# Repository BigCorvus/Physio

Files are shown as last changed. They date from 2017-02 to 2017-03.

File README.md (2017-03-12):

# Physio
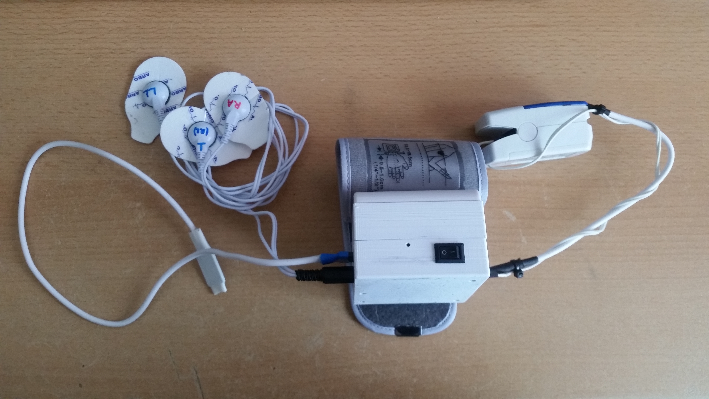
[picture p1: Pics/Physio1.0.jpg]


My take on an (almost) open source development platform for a versatile wireless monitoring device that combines ECG, impedance pneumography, photoplethysmography, SPO2 calculation, galvanic skin response, NIBP wrist measurement as well as well as body temperature measurement in one wearable. 

Physio is based on a CK101 wrist blood pressure monitor, a CMS50C pulse oximeter, an ADS1292R analog front end for ECG and impedance pneumography (respiration monitoring via ECG electrodes), a MAX30205 human body temperature sensor and an ADXL345 accelerometer. The GSR measurement is also working fine so far, but it's interfering with the ADS1292R so only one of them can be used at a time. For instruction on hacking the CK101 and CMS50C see  my blog posts http://www.thinkering.de/cms/?p=833 and http://www.thinkering.de/cms/?p=864. and A Teensy 3.2 ties everythings together and uses an HC-05 bluetooth module for communication.
The carrier PCB of the current Physio version is designed for the great ADS1292R breakout board by protocentral->https://github.com/Protocentral/ADS1292rShield_Breakout

The Android app is based on the Amarino platform, so you have to download and install the Amarino App in order for this app to work (https://storage.googleapis.com/google-code-archive-downloads/v2/code.google.com/amarino/Amarino_2_v0_55.apk). The recording feature is not working yet and will be improved in the future.

In order to get the best ECG and respiration data I recommend placing the electrodes according to the "Einthoven II" lead.

Short demo video with crappy electrodes: https://youtu.be/U5jK3dh345U

Note: this is not a medical device, but a development platform for educational and research purposes. I'm assuming you know what you're doing.

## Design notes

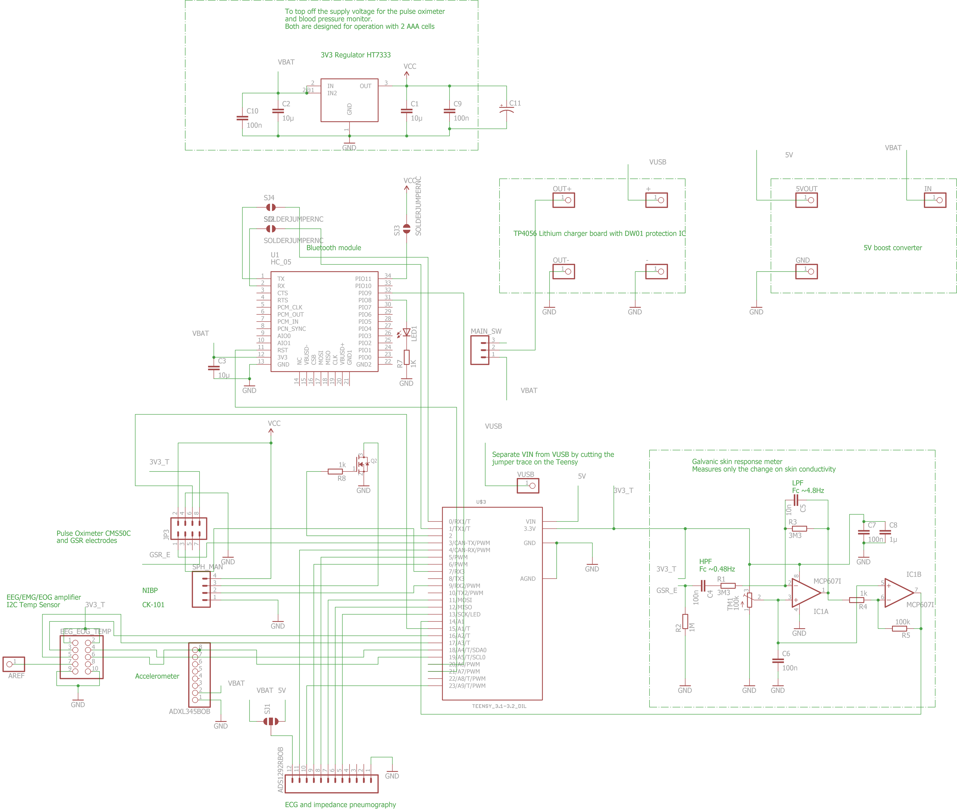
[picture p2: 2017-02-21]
Hardware/Physio_v1.0.png

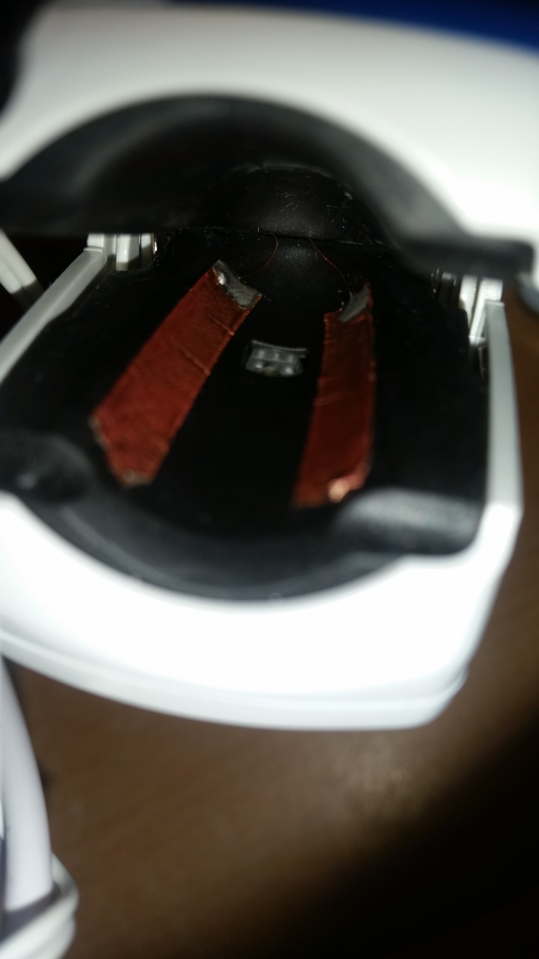
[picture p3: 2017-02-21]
Pics/GSR_pulseox.jpg

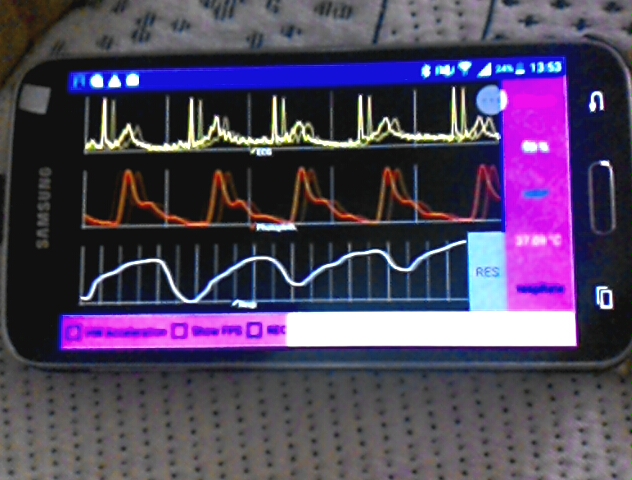
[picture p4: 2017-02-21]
Pics/android app.jpg

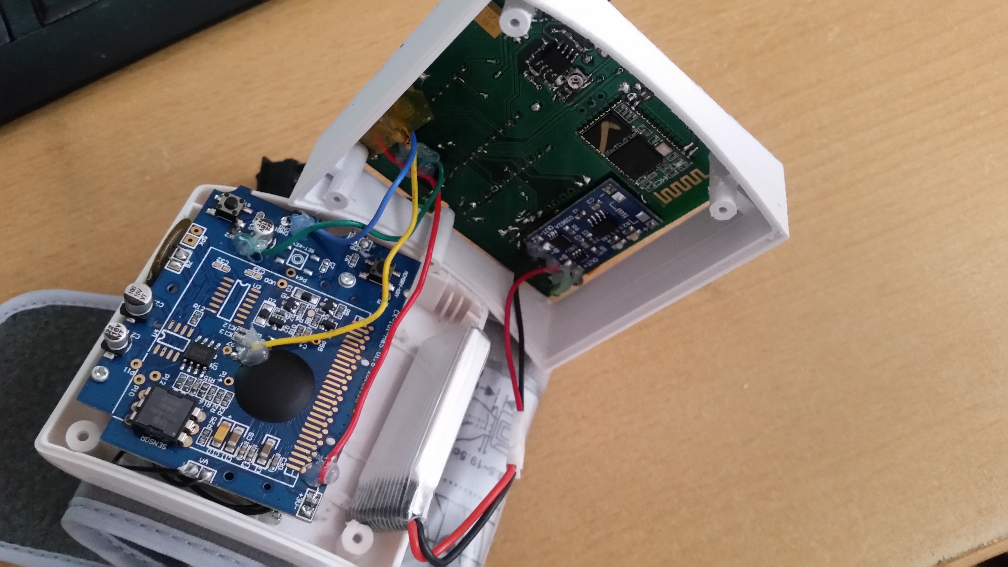
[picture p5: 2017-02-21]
Pics/Physio1.0inside.jpg

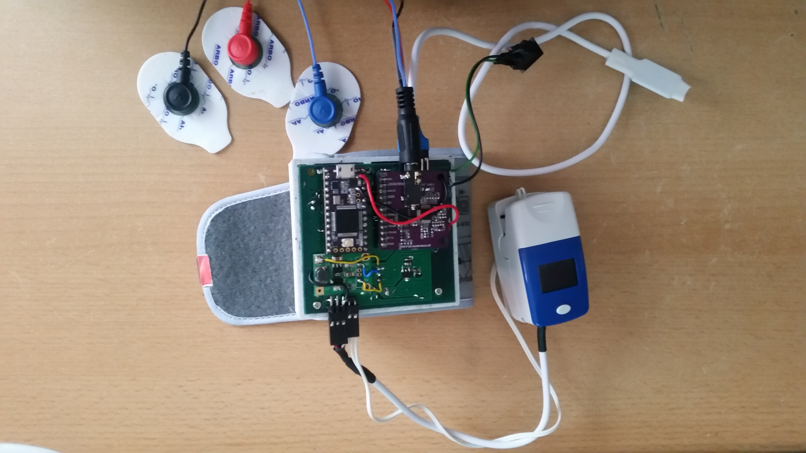
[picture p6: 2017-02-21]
Pics/Physio1.0inside2.jpg

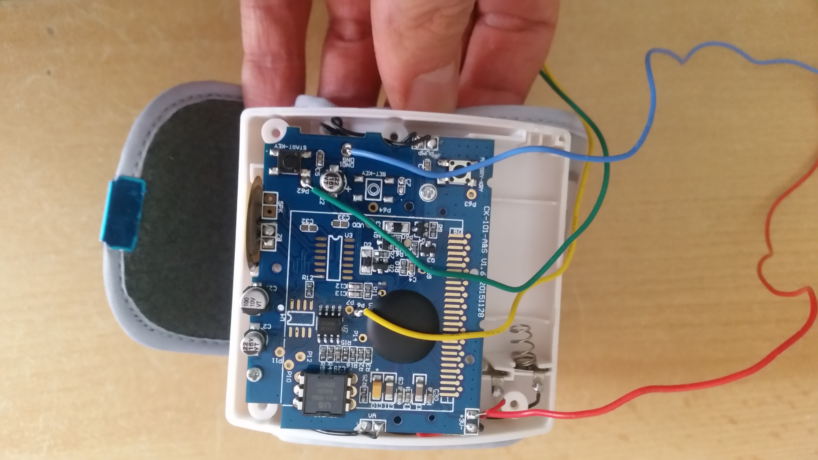
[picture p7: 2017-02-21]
Pics/CK101connections.jpg

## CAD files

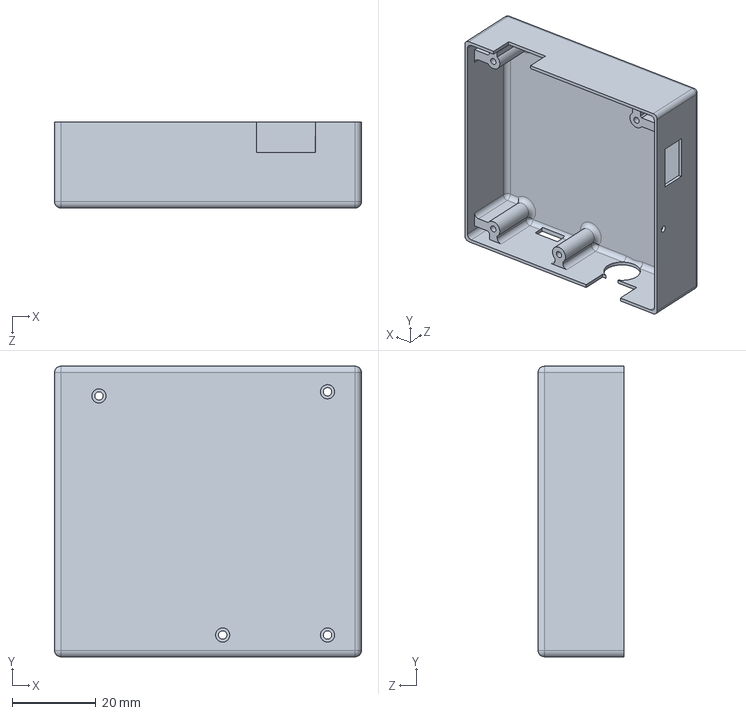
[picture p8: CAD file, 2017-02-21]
Enclosure Design/Physio_enclTop.SLDPRT
73.2 x 69.3 x 20.5 mm

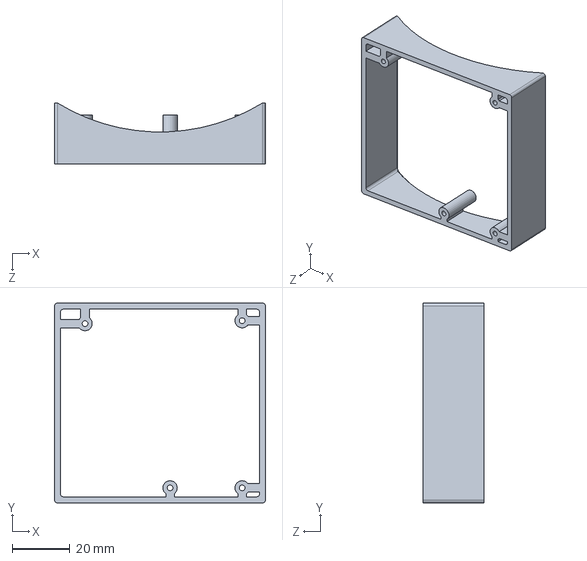
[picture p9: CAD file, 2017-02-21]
Enclosure Design/Physio_encl.SLDPRT
73.2 x 69.3 x 21.0 mm

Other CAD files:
Enclosure Design/Physio_encl.STL
Enclosure Design/Physio_enclTop.STL

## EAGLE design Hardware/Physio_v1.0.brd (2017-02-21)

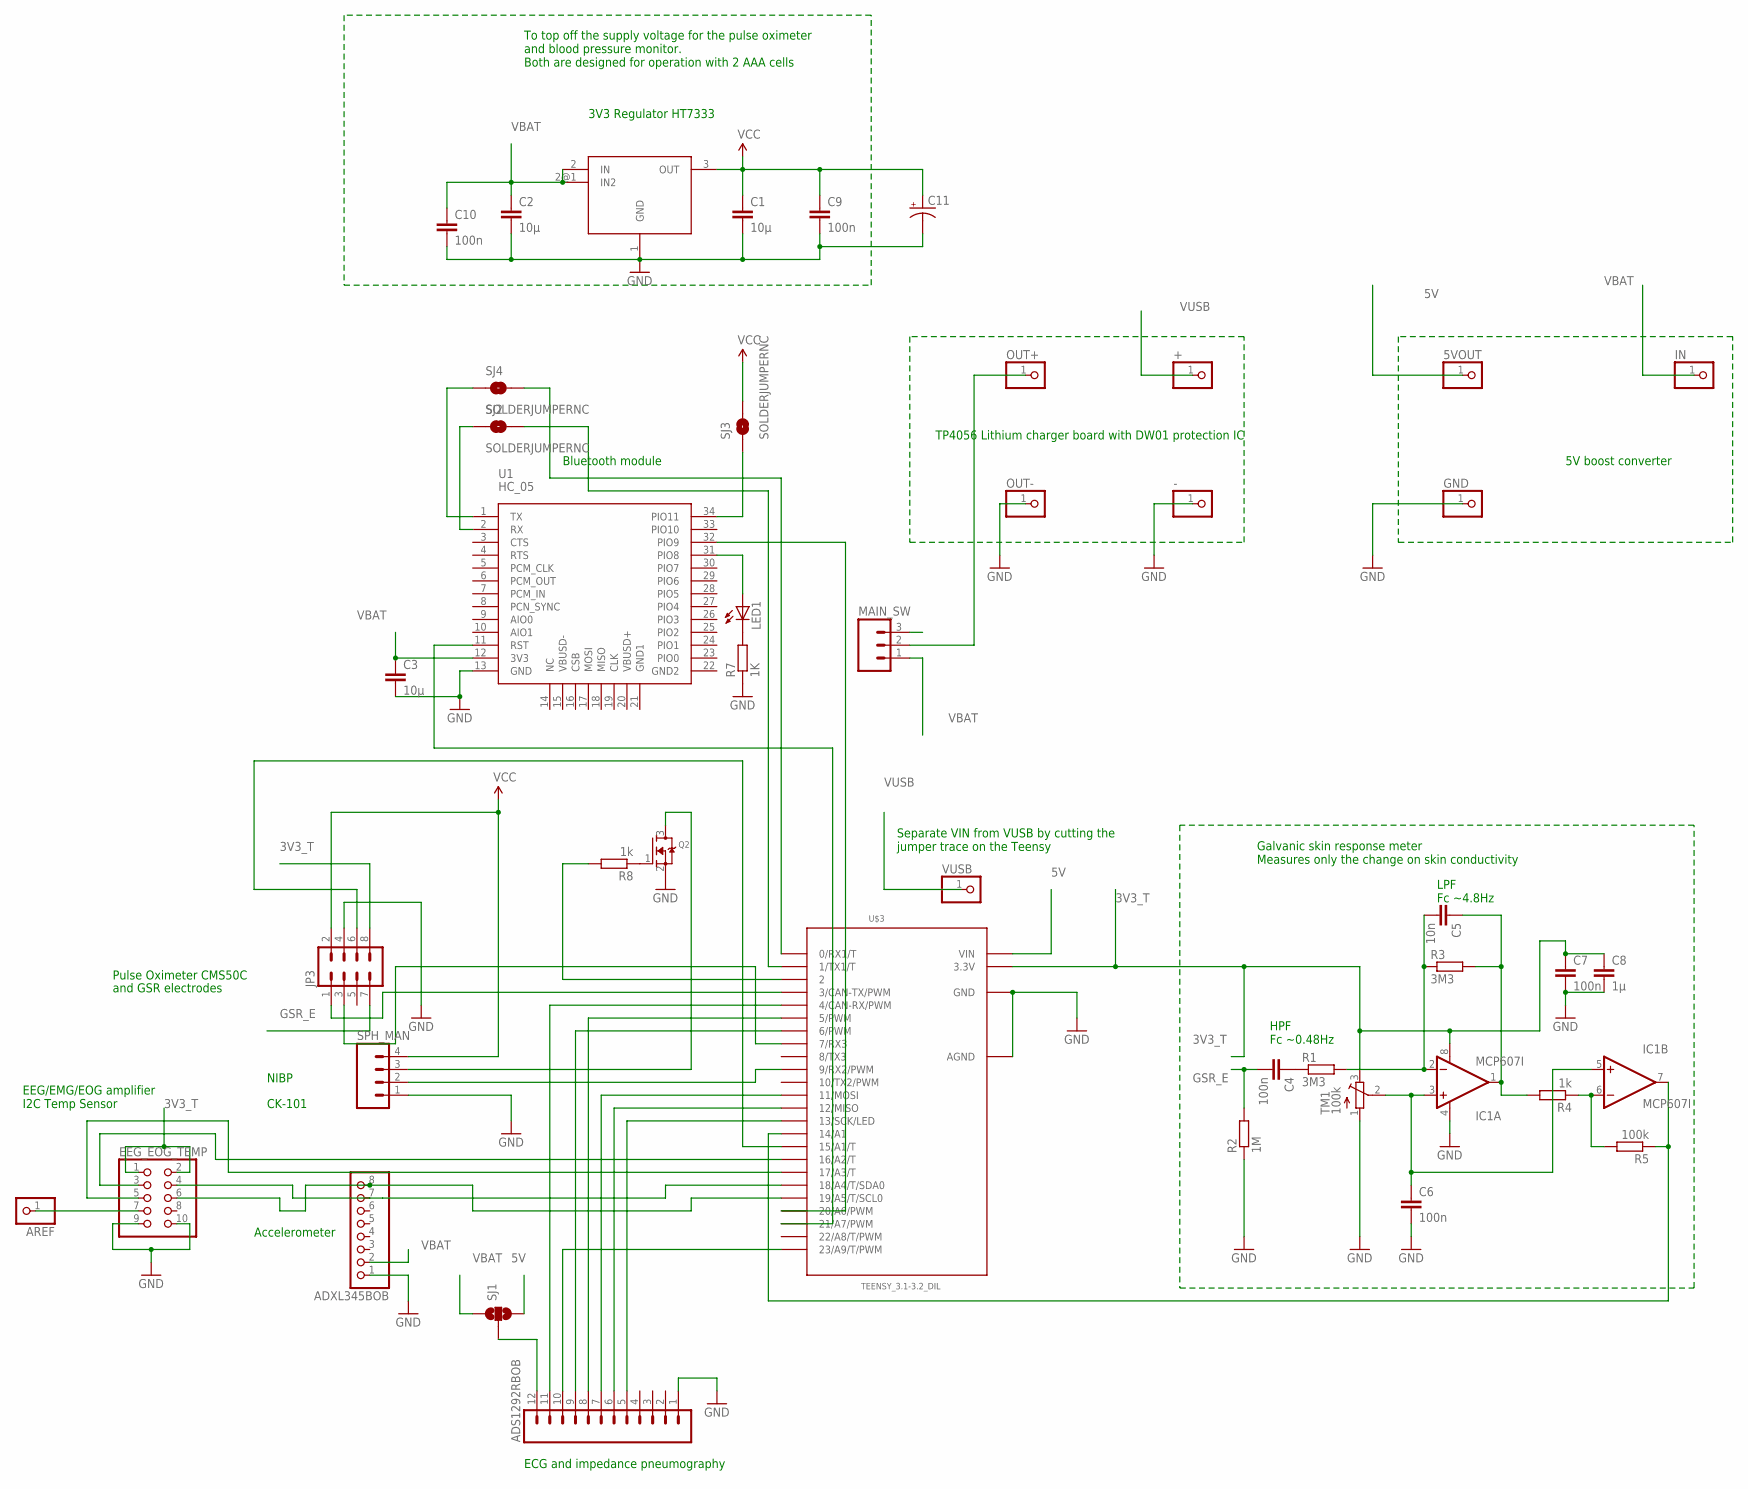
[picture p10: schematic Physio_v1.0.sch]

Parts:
5VOUT: PINHD-1X1; 1X01
+: PINHD-1X1; 1X01
-: PINHD-1X1; 1X01
ADS1292RBOB: M12PTH; 1X12
ADXL345BOB: PINHD-1X8CLEANBIG; 1X08-CLEANBIG
AREF: PINHD-1X1; 1X01
C1, C2, C3: 10µ; C0805K
C4, C6, C7, C9, C10: 100n; C0603K
C5: 10n; C0603K
C8: 1µ; C0603K
C11: CAP_POL7343; EIA7343
EEG_EOG_TEMP: PINHD-2X5/90; 2X05/90
GND: PINHD-1X1; 1X01
IC1: MCP607I; SO08
IN: PINHD-1X1; 1X01
JP3: M04X2; 2X4
LED1: LEDCHIP-LED0805; CHIP-LED0805
MAIN_SW: M03PTH; 1X03
OUT+: PINHD-1X1; 1X01
OUT-: PINHD-1X1; 1X01
Q2: MOSFET-NREFLOW; SOT23
R1, R3: 3M3; R0603
R2: 1M; R0603
R4, R8: 1k; R0603
R5: 100k; R0603
R7: 1K; R0603
SJ1: SOLDERJUMPER_2WAY-OLDT; SJ_2
SJ2, SJ3, SJ4: SOLDERJUMPERNC; SJ_2S
SPH_MAN: M04PTH; 1X04
TM1: 100k; TC33X
U1: HC_05; BLUETOOTH_SMD
U$2: HT7333; SOT89
U$3: TEENSY_3.1-3.2_DIL; TEENSY_3.0-3.2&LC_DIL
VUSB: PINHD-1X1; 1X01

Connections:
3V3_T: C7.1, C8.1, EEG_EOG_TEMP.1, EEG_EOG_TEMP.2, IC1.8 (V+), JP3.8, TM1.3 (E), U$3.3.3V
5V: 5VOUT.1, SJ1.3, U$3.VIN
GND: -.1, ADS1292RBOB.1, ADXL345BOB.1, C1.2, C2.2, C3.2, C6.2, C7.2, C8.2, C9.2, C10.2, C11.C (-), EEG_EOG_TEMP.9, EEG_EOG_TEMP.10, GND.1, IC1.4 (V-), JP3.4, OUT-.1, Q2.2 (S), R2.1, R7.1, SPH_MAN.1, TM1.1 (A), U1.13 (GND), U$2.1 (GND), U$3.AGND, U$3.GND
GSR_E: C4.2, JP3.7, R2.2
unnamed: JP3.1, U$3.3 (3/CAN-TX/PWM)
unnamed: SPH_MAN.2, U$3.9 (9/RX2/PWM)
unnamed: JP3.3, U$3.7 (7/RX3)
unnamed: Q2.3 (D), SPH_MAN.3
unnamed: SJ4.2, U$3.0 (0/RX1/T)
unnamed: SJ2.2, U$3.1 (1/TX1/T)
unnamed: ADS1292RBOB.7, U$3.11 (11/MOSI)
unnamed: ADS1292RBOB.6, U$3.12 (12/MISO)
unnamed: ADS1292RBOB.5, U$3.13 (13/SCK/LED)
unnamed: ADS1292RBOB.9, U$3.6 (6/PWM)
unnamed: ADS1292RBOB.8, U$3.5 (5/PWM)
unnamed: ADS1292RBOB.11, U$3.4 (4/CAN-RX/PWM)
unnamed: ADS1292RBOB.10, U$3.23/A9 (23/A9/T/PWM)
unnamed: C5.2, IC1.2 (-IN), R1.2, R3.1
unnamed: C5.1, IC1.1 (OUT), R3.2, R4.2
unnamed: C6.1, IC1.3 (+IN), IC1.5 (+IN), TM1.2 (S)
unnamed: C4.1, R1.1
unnamed: SJ4.1, U1.1 (TX)
unnamed: IC1.6 (-IN), R4.1, R5.2
unnamed: IC1.7 (OUT), R5.1, U$3.14/A0 (14/A1)
unnamed: SJ2.1, U1.2 (RX)
unnamed: JP3.6, U$3.15/A1 (15/A1/T)
unnamed: ADXL345BOB.8, EEG_EOG_TEMP.6, U$3.19/A5 (19/A5/T/SCL0)
unnamed: ADXL345BOB.7, EEG_EOG_TEMP.4, U$3.18/A4 (18/A4/T/SDA0)
unnamed: LED1.C, R7.2
unnamed: LED1.A, U1.31 (PIO8)
unnamed: EEG_EOG_TEMP.3, U$3.16/A2 (16/A2/T)
unnamed: EEG_EOG_TEMP.5, U$3.17/A3 (17/A3/T)
unnamed: R8.2, U$3.2
unnamed: ADS1292RBOB.12, SJ1.2
unnamed: Q2.1 (G), R8.1
unnamed: AREF.1, EEG_EOG_TEMP.7
unnamed: MAIN_SW.2, OUT+.1
unnamed: U1.32 (PIO9), U$3.20/A6 (20/A6/PWM)
unnamed: U1.11 (RST), U$3.21/A7 (21/A7/PWM)
unnamed: SJ3.1, U1.34 (PIO11)
VBAT: ADXL345BOB.2, C2.1, C3.1, C10.1, IN.1, MAIN_SW.1, SJ1.1, U1.12 (3V3), U$2.2 (IN), U$2.2@1 (IN2)
VCC: C1.1, C9.1, C11.A (+), JP3.2, SJ3.2, SPH_MAN.4, U$2.3 (OUT)
VUSB: +.1, VUSB.1

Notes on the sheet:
Galvanic skin response meter Measures only the change on skin conductivity
HPF Fc ~0.48Hz
LPF Fc ~4.8Hz
ECG and impedance pneumography
Accelerometer
NIBP
CK-101
Pulse Oximeter CMS50C
EEG/EMG/EOG amplifier I2C Temp Sensor
3V3 Regulator HT7333
Separate VIN from VUSB by cutting the jumper trace on the Teensy
TP4056 Lithium charger board with DW01 protection IC
5V boost converter
To top off the supply voltage for the pulse oximeter and blood pressure monitor. Both are designed for operation with 2 AAA cells
Bluetooth module
and GSR electrodes

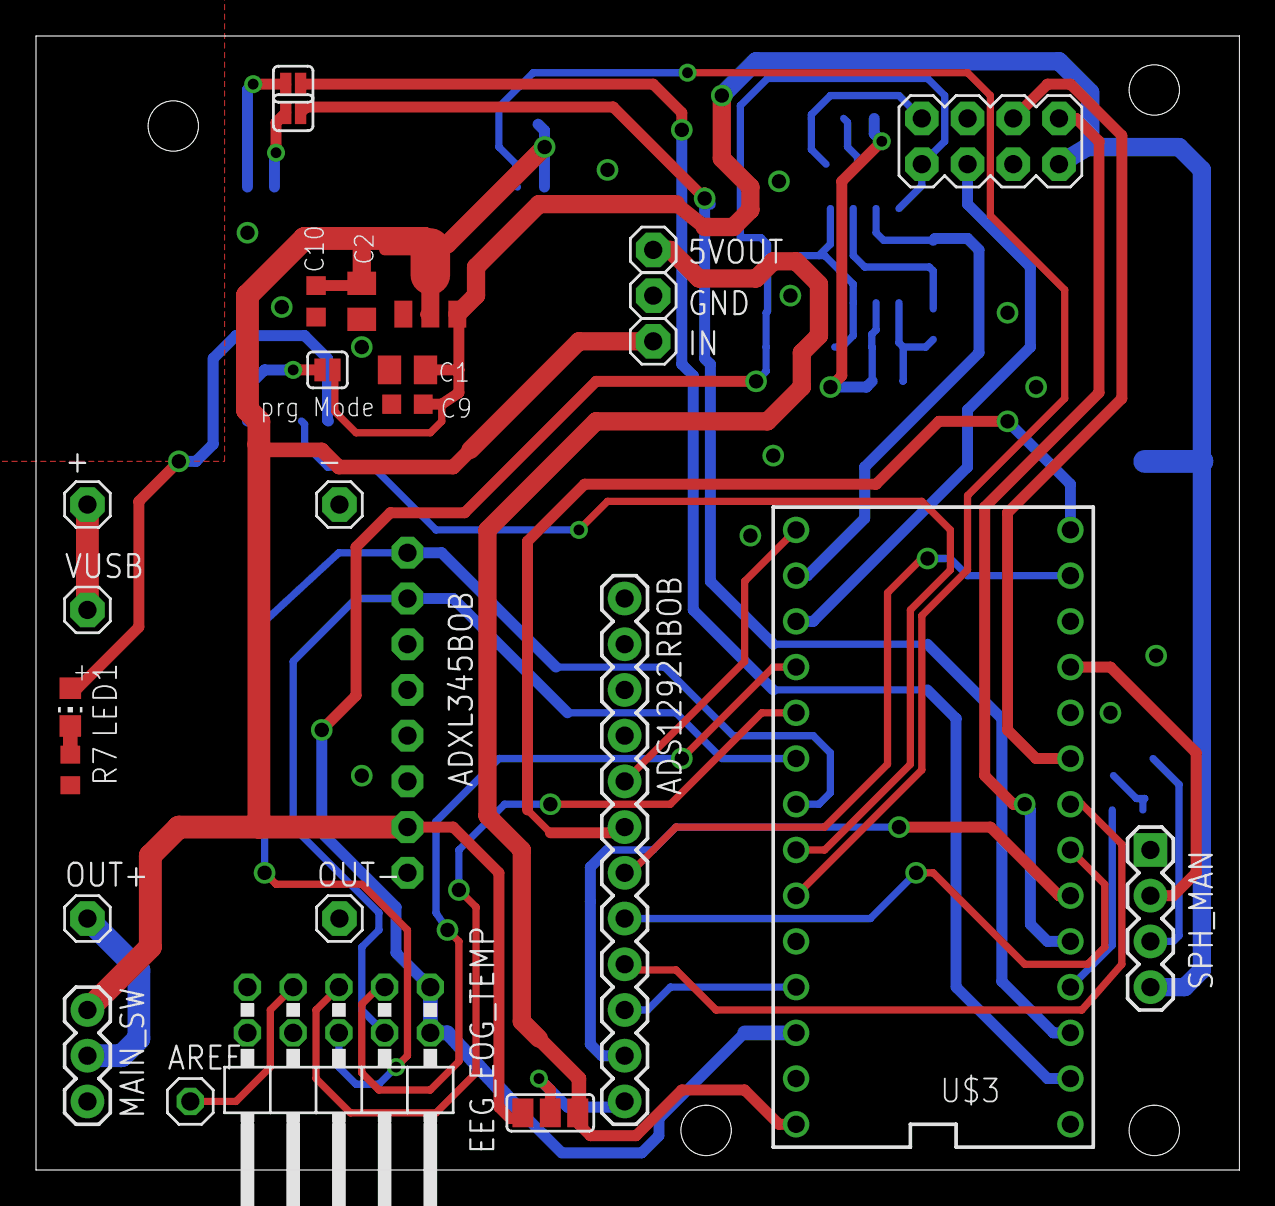
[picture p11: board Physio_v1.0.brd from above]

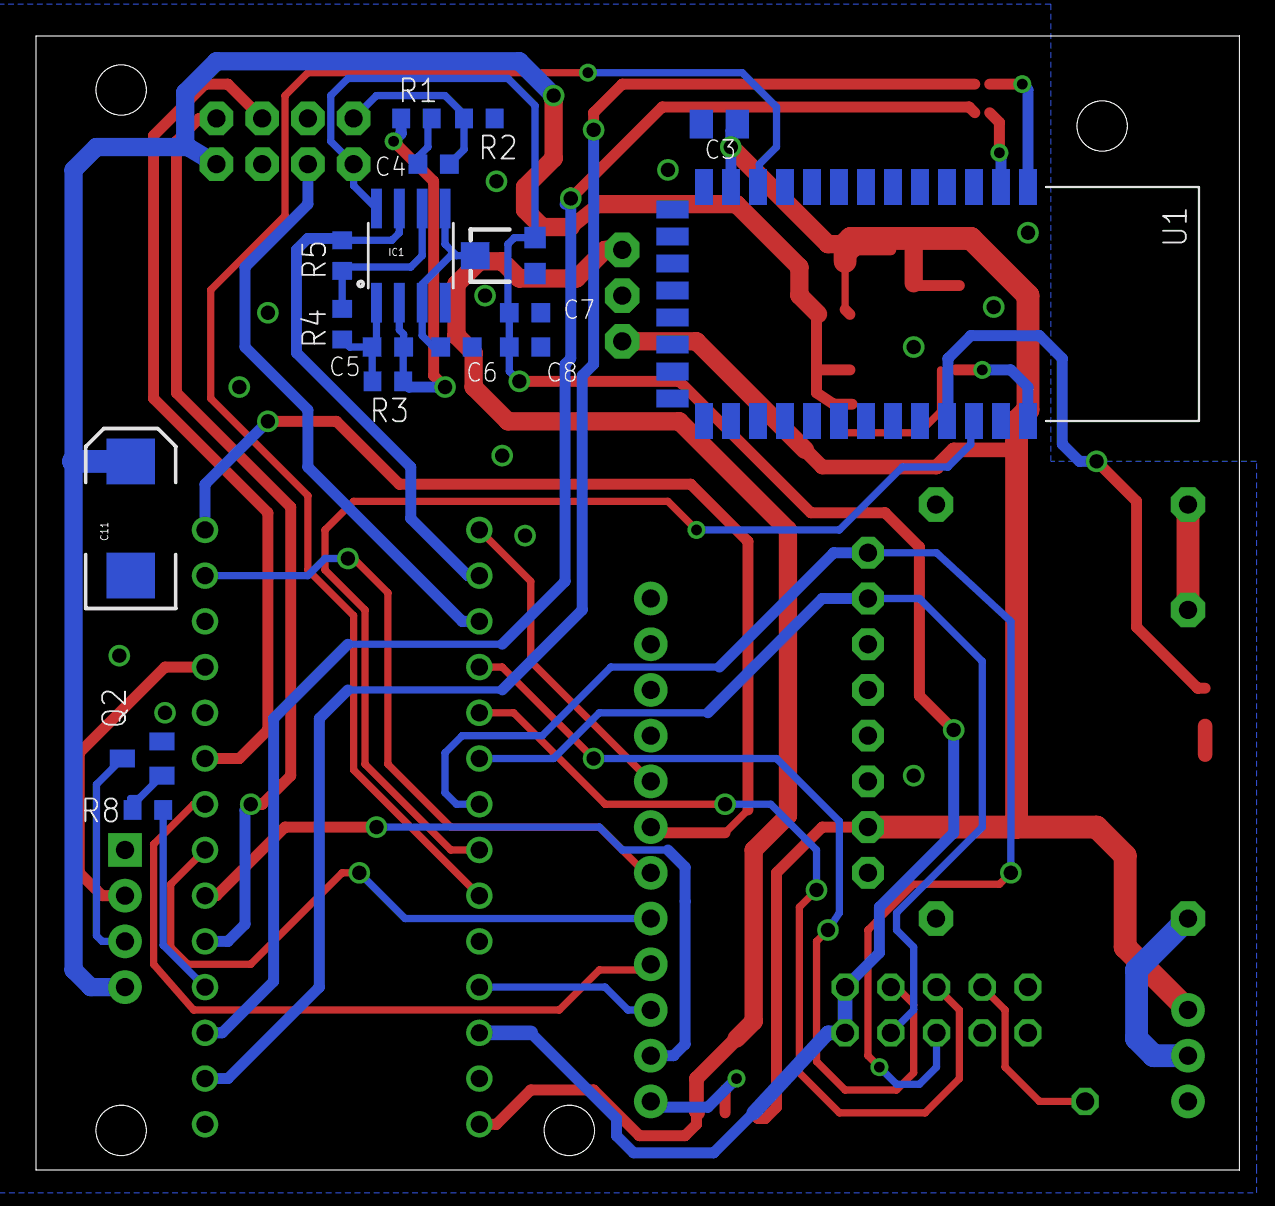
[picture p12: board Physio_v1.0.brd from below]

Board: 2 copper layers, 66.9 x 63.0 mm, 44 parts (17 on the bottom side), 43 nets.

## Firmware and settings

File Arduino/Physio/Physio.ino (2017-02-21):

/*
  Patient Monitor with Blood pressure monitor CK-101 and Pulse oximeter CONTEC CMS 50C
  On Teensy 3.1
*/
// Arduino Wire library is required if I2Cdev I2CDEV_ARDUINO_WIRE implementation
// is used in I2Cdev.h
#include "Wire.h"
// I2Cdev and ADXL345 must be installed as libraries, or else the .cpp/.h files
// for both classes must be in the include path of your project
#include "I2Cdev.h"
#include "ADXL345.h"

#include <ads1292r.h>
#include <SPI.h>
#include <MeetAndroid.h> //modified library that uses Serial1 instead of Serial!
#include "ClosedCube_MAX30205.h"


//--------------------------------------ADS1292R stuff----------------------------------

uint8_t DataPacketHeader[16];
ads1292r ADS1292;
//Packet format
#define  CES_CMDIF_PKT_START_1   0x0A
#define CES_CMDIF_PKT_START_2   0xFA
#define CES_CMDIF_TYPE_DATA   0x02
#define CES_CMDIF_PKT_STOP    0x0B

uint8_t data_len = 8;
unsigned long time;

volatile byte SPI_RX_Buff[150] ;
volatile static int SPI_RX_Buff_Count = 0;
volatile char *SPI_RX_Buff_Ptr;
volatile int Responsebyte = false;
volatile unsigned int pckt = 0 , buff = 0, t = 0 , jone = 0, jtwo = 0;
volatile unsigned long int RESP_Ch1_Data[150], ECG_Ch2_Data[150];
volatile unsigned char datac[150];
unsigned long uecgtemp = 0, Pkt_Counter = 0;
long ECG, RESP = 0;
signed long secgtemp = 0;
volatile int i;
volatile long packet_counter = 0;
//--------------------------------------ADS1292R stuff----------------------------------

// class default I2C address is 0x53
// specific I2C addresses may be passed as a parameter here
// ALT low = 0x53 (default for SparkFun 6DOF board)
// ALT high = 0x1D
ADXL345 accel;
ClosedCube_MAX30205 max30205; //human temperature sensor connected over I2C
// declare MeetAndroid so that you can call functions with it
MeetAndroid meetAndroid;
int16_t ax, ay, az;


//pins for switching the start buttons on the medical gadgets

#define TRIG_RR 2 //has to be pulled to ground to start the CK-101
#define TRIG_PULSEOX 3 // has to be pulled to 3.3V to start the CMS50C
#define RST_PULSEOX 15

//packet management bytes for the Amarino Android app
char startFlag = 18;
char ack = 19;
char delimiter = 59; //';' in case we use more than 1 channel

//vars for RR
boolean isMeasuringRR = false;
boolean RRdoneByteCame = false;
boolean successfulRR = false;
boolean readSpecialPacket = false;
boolean errorRR = false;
char incomingRRbyte;
int byteCntRR = 0;
char pulseCurve_RR;
char cuffPressRR;
char systRR;
char diastRR;
char HR_RR;

//vars for pulseOx
char incomingPulseOxbyte;
unsigned int byteCntPulse = 0;
char pulseCurve_PulseOx = 0;
char SPO2;
char HR_PulseOx;
boolean lastBitPulseOx = 0; //the MSB of the heart rate byte is hidden in a different byte - the one that holds the bar graph data

//timer vars
unsigned long GSRTmr, temperatureTmr = 0;
unsigned long sampIntGSR=50000;//sample interval for GSR measurement, Accelerometer, impedance pneumography value
unsigned long sampIntTemp=500000;//sample interval for the temperature sensor

unsigned long RRtrigTmr=0;
unsigned long RRtrigInt=200000; // length of the pulse that triggers the CK-101 button via NPN transistor
unsigned long pulseOxTrigTmr=0;
unsigned long pulseOxTrigInt=600000; // length of the pulse that triggers the CMS50C
unsigned long pulseOxRstTmr=0;
unsigned long pulseOxRstInt=800000;
boolean triggered = false;
boolean triggeredOx = false;
boolean resettedOx = false;
//----------------------------------------------------------------------------------------------------

void setup() {
  // initialize serial:
  Serial1.begin(115200); // Bluetooth port
  Serial2.begin(9600); // Blood pressure monitor CK-101 port
  Serial3.begin(4800, SERIAL_8E1); // Pulse oximeter CONTEC CMS 50C, annoying fact: it has EVEN PARITY!

  // initalize the  data ready and chip select pins for ADS1292R:
  pinMode(ADS1292_DRDY_PIN, INPUT);  //6
  pinMode(ADS1292_CS_PIN, OUTPUT);    //7
  pinMode(ADS1292_START_PIN, OUTPUT);  //5
  pinMode(ADS1292_PWDN_PIN, OUTPUT);  //4

  // make the pins outputs:
  pinMode(RST_PULSEOX, OUTPUT);
  pinMode(TRIG_RR, OUTPUT);
  pinMode(TRIG_PULSEOX, OUTPUT);
  
  digitalWrite(RST_PULSEOX, HIGH);
  digitalWrite(TRIG_RR, LOW);
  
  triggerOx(); //turn on the PulseOx
  // join I2C bus (I2Cdev library doesn't do this automatically)
  Wire.begin();
  accel.initialize();
  max30205.begin(0x48); //initialize the temp sensor
  //initalize ADS1292 slave
  ADS1292.ads1292_Init();
  //ADS1292.ads1292_Reset();
  // register callback functions, which will be called when an associated event occurs.
  meetAndroid.registerFunction(measureRR, 'b');


  GSRTmr=micros(); //GSR, RESP, ACC are sampled simultaneously
  temperatureTmr=micros(); //temperature is sampled slower
}
//----------------------------------------------------------------------------------------------------

void loop() {

//waiting to pull TRIG_RR LOW again to turn the NPN transistor off
  if((micros()-RRtrigTmr)>RRtrigInt && triggered == true){
    digitalWrite(TRIG_RR, LOW);
    triggered=false;
  }

  //waiting to pull TRIG_PULSEOX LOW again 
  if((micros()-pulseOxTrigTmr)>pulseOxTrigInt && triggeredOx == true){
    digitalWrite(TRIG_PULSEOX, LOW);
    triggeredOx=false;
  }
  
 //waiting pulseOxRstInt long after Reset and then trigger the Oximeter to turn it on again 
 //probably not necessary
  if((micros()-pulseOxRstTmr)>pulseOxRstInt && resettedOx == true){
     byteCntPulse=0; //clean up after reset
    resettedOx=false;
    triggerOx();
  }
  
/*
  //waiting to pull RST_PULSEOX HIGH again 
  if((micros()-pulseOxRstTmr)>pulseOxRstInt && resettedOx == true){
    digitalWrite(RST_PULSEOX, HIGH);
    resettedOx=false;
//after reset push its button
    digitalWrite(TRIG_PULSEOX, HIGH); //push its button
           pulseOxTrigTmr=micros();
           triggeredOx=true;
  }

  */
  
  sampleTemperature();

  sampleDevices();

  meetAndroid.receive(); // you need to keep this in your loop() to receive events

  readADS();

  readPulseOx();

  readBloodPress();

}

//------------------------------------functions for the components--------------------------------------------------

void sampleDevices(){
  //sample GSR, Respiration, Accelerometer
  if((micros() - GSRTmr) > sampIntGSR){
  Serial1.print(startFlag);
  Serial1.print("G");
  //Serial1.print(delimiter);
  Serial1.print(analogRead(A0), DEC);
  Serial1.print(delimiter);
  Serial1.print(RESP, DEC);
  //Serial1.print(ack);

  // read raw accel measurements from device
  accel.getAcceleration(&ax, &ay, &az);
  //Serial1.print(startFlag);
  //Serial1.print("A");
  Serial1.print(delimiter);
  Serial1.print(ax, DEC);
  Serial1.print(delimiter);
  Serial1.print(ay, DEC);
  Serial1.print(delimiter);
  Serial1.print(az, DEC);
  Serial1.print(ack);
  GSRTmr=micros();
  }
}

void sampleTemperature(){
//sample temperature
  if((micros()-temperatureTmr) > sampIntTemp){
  Serial1.print(startFlag);
  Serial1.print("T");
 // Serial1.print(delimiter);
  Serial1.print(max30205.readTemperature());
  Serial1.print(ack);
  temperatureTmr=micros();
  }
  
}

void readADS() {
  //----------------------------------ADS1292R code-------------------------------------------------

  if ((digitalRead(ADS1292_DRDY_PIN)) == LOW)
  {
    SPI_RX_Buff_Ptr = ADS1292.ads1292_Read_Data();
    Responsebyte = true;
    //Serial1.print("DRDY low: ");
  }

  if (Responsebyte == true)
  {
    /*Serial1.print("start Time: ");
      time = millis();
      //prints time since program started
      Serial1.println(time);
    */
    for (i = 0; i < 9; i++)
    {
      SPI_RX_Buff[SPI_RX_Buff_Count++] = *(SPI_RX_Buff_Ptr + i);
    }
    Responsebyte = false;
  }

  if (SPI_RX_Buff_Count >= 9)
  {
    pckt = 0; jone = 0;   jtwo = 0;
    for (i = 3; i < 9; i += 9)
    {
      //udi_cdc_putc(SPI_RX_Buff[i]);
      //RESP_Ch1_Data[jone++]=  SPI_RX_Buff[i+0];
      //RESP_Ch1_Data[jone++]= SPI_RX_Buff[i+1];
      //RESP_Ch1_Data[jone++]= SPI_RX_Buff[i+2];

      ECG_Ch2_Data[jtwo++] = (unsigned char)SPI_RX_Buff[i + 3];
      ECG_Ch2_Data[jtwo++] = (unsigned char)SPI_RX_Buff[i + 4];
      ECG_Ch2_Data[jtwo++] = (unsigned char)SPI_RX_Buff[i + 5];

      RESP_Ch1_Data[jone++] = (unsigned char)SPI_RX_Buff[i + 0];
      RESP_Ch1_Data[jone++] = (unsigned char)SPI_RX_Buff[i + 1];
      RESP_Ch1_Data[jone++] = (unsigned char)SPI_RX_Buff[i + 2];
    }

    packet_counter++;

    uecgtemp = (unsigned long) ((ECG_Ch2_Data[0] << 16) | (ECG_Ch2_Data[1] << 8) | ECG_Ch2_Data[2]);
    uecgtemp = (unsigned long) (uecgtemp << 8);
    //secgtemp = (signed long) (uecgtemp);
    //secgtemp = (signed long) (secgtemp>>8);
    ECG = uecgtemp + 134217728; //(unsigned int) ((ECG_Ch2_Data[0]<<16)|(ECG_Ch2_Data[1]<<8)|ECG_Ch2_Data[2]);//uecgtemp;//map(uecgtemp,0,4294967296,0,65535);
    ECG = ECG/16;
    //if(ECG>4194304 || ECG<12582912)
    //ECG=map(ECG,4194304,12582912,0,16777216);
    
    Serial1.print(startFlag);
    Serial1.print("E");
    //Serial1.print(delimiter);
    Serial1.print(ECG, DEC);
    Serial1.print(ack);
    uecgtemp = (unsigned long) ((RESP_Ch1_Data[0] << 16) | (RESP_Ch1_Data[1] << 8) | RESP_Ch1_Data[2]);
    uecgtemp = (unsigned long) (uecgtemp << 8);
    RESP = uecgtemp + 134217728; //(unsigned int) ((RESP_Ch1_Data[0]<<16)|(RESP_Ch1_Data[1]<<8)|RESP_Ch1_Data[2]);
    RESP=RESP/256;
    //RESP = map(RESP, 0, 8388608, 0, 9999);
    //secgtemp = (signed long) (uecgtemp);
    //secgtemp = (signed long) (secgtemp>>8);
  }
  SPI_RX_Buff_Count = 0;
}

void readBloodPress() {

  //--------------------Blood pressure data analysis----------------

  if (Serial2.available() > 0) {
    //RR data
    incomingRRbyte = Serial2.read();

    switch (byteCntRR) {
      case 0:

        if (readSpecialPacket == false && successfulRR == false) {
          Serial1.print(startFlag);
          Serial1.print("r");
          //Serial1.print(delimiter);
          Serial1.print(cuffPressRR, DEC); //send the pulse curve value
          Serial1.print(delimiter);
          Serial1.print(pulseCurve_RR, DEC); //send the heart rate
          Serial1.print(ack);
        }
        break;

      case 1:
        if (readSpecialPacket == false) {
          cuffPressRR = incomingRRbyte;
          isMeasuringRR = true;

        }

        if (incomingRRbyte == 8) { //if the third byte after 255 254 is 008 we had a successful measurement!
          isMeasuringRR = false;
        }
        if (incomingRRbyte == 3) { //if the third byte after 255 254 is 003 - it's the beginning sequence!


        }
        if (incomingRRbyte == 4) { //oh no, measurement was not successful!

          errorRR = true;

        }
        byteCntRR++;

        break;

      case 2:
        if (readSpecialPacket == false) {
          pulseCurve_RR = incomingRRbyte;
          successfulRR = false;
          byteCntRR = 0;
        } else {
          byteCntRR++;


        }

        if (incomingRRbyte == 83) { //beginning sequence

        }
        if (incomingRRbyte == 93) { //error sequence

        }
        if (incomingRRbyte == 98) { //if measurement was successful

        }
        break;

      case 3: //dunno what this byte means yet
        if (incomingRRbyte == 80) { //beginning sequence
          byteCntRR = 0; //entry sequence ends after this byte
          readSpecialPacket = false;
          isMeasuringRR = true;
          successfulRR = false;
          // Serial1.print("Begun");
        } else {
          byteCntRR++;

        }
        if (incomingRRbyte == 86) { //error sequence

        }
        if (incomingRRbyte == 85) { //if measurement was successful

        }
        //if you are not in special packet mode stop here
        if (readSpecialPacket == false)
          byteCntRR = 0;
        break;

      case 4:
        if (incomingRRbyte == 3) { //error sequence
          byteCntRR = 0; //error sequence ends here
          readSpecialPacket = false;
          isMeasuringRR = false;
          Serial1.print(startFlag);
          Serial1.print("RRerr");
          Serial1.print(ack);

          digitalWrite(RST_PULSEOX, HIGH);
pulseOxRstTmr=micros();
   resettedOx=true;
        } else
          byteCntRR++;
        if (incomingRRbyte == 0) { //if measurement was successful

        }

        break;

      case 5: // syst. low byte
        systRR = incomingRRbyte;
        byteCntRR++;

        break;
      case 6:
        //syst. high byte
        systRR = 256 * incomingRRbyte + systRR; //in case anyone has a blood pressure above 255 mmHg!
        byteCntRR++;
        break;

      case 7: //diastolic pressure
        diastRR = incomingRRbyte;
        byteCntRR++;
        break;

      case 8: //heart rate measured by the blood pressure monitor
        HR_RR = incomingRRbyte;

        successfulRR = true;
        byteCntRR = 0;
        readSpecialPacket = false;

        if (successfulRR) {
          Serial1.print(startFlag);
          Serial1.print("R");
          //Serial1.print(delimiter);
          Serial1.print(systRR, DEC);
          Serial1.print(delimiter);
          Serial1.print(diastRR, DEC);
          Serial1.print(delimiter);
          Serial1.print(HR_RR, DEC);
          Serial1.print(ack);
digitalWrite(RST_PULSEOX, HIGH);
pulseOxRstTmr=micros();
   resettedOx=true;
          //  triggerOx();
          
//digitalWrite(RST_PULSEOX, LOW);
//resettedOx=true;
 //pulseOxRstTmr=micros();      
        }

        break;

      default:
        break;
    }

    if (incomingRRbyte == 255 ) { //if during measurement 255 appears as a pressure value, this is not supposed to trigger!!!!
      if (byteCntRR == 0 && isMeasuringRR == false)
        RRdoneByteCame = true;
      //Serial1.print("255came");
    }

    if ( incomingRRbyte == 254 ) {
      byteCntRR++;
      if (RRdoneByteCame == true) {
        readSpecialPacket = true;
        RRdoneByteCame = false;
      }

    }

  }
}

void readPulseOx() {
  if (successfulRR) digitalWrite(RST_PULSEOX, HIGH);
  //--------------------Pulse Oximeter data analysis----------------
  if (Serial3.available() > 0) {
    //pulseox data
    incomingPulseOxbyte = Serial3.read();
    if (byteCntPulse == 1) {
      //the second byte contains a 7 bit pulse wave value, Fs=60Hz
      pulseCurve_PulseOx = incomingPulseOxbyte;
      byteCntPulse++;
    } else if (byteCntPulse == 2) {
      //the 0-3rd bits of the third byte is the bar graph value .
      //the 6th bit is bit 7 of the heart rate value!
      if ( bitRead(incomingPulseOxbyte, 6)) {
        //if the heart rate is >= 128, this happens
        lastBitPulseOx = 1;
      } else
        lastBitPulseOx = 0;

      byteCntPulse++; //move on
    } else if (byteCntPulse == 3) {
      //
      if (lastBitPulseOx)
        //if the heart rate is >= 128, this happens
        HR_PulseOx = 128 + incomingPulseOxbyte;
      else
        HR_PulseOx = incomingPulseOxbyte;

      byteCntPulse++;
    } else if (byteCntPulse == 4) {
      //the last byte contains the most important SPO2 value
      SPO2 = incomingPulseOxbyte;
      byteCntPulse = 0; //we're done the data packet has 5 bytes in total
    } else {


      Serial1.print(startFlag);
      Serial1.print("P");
      //Serial1.print(delimiter);
      Serial1.print(pulseCurve_PulseOx, DEC); //send the pulse curve value
      Serial1.print(delimiter);
      Serial1.print(HR_PulseOx, DEC); //send the heart rate
      Serial1.print(delimiter);
      Serial1.print(SPO2, DEC); //send SPO2 value!
      Serial1.print(ack);

    }

    //analyze the first byte. it has plenty of information about the data
    //the fourth bit of the first packet byte means "OK signal" if zero, otherwise it stands for "searching too long"
    //the seventh bit of the first byte has to be always set!!!!! (the only byte where this is the case) all other bytes have a bit 7 == 0
    if ( bitRead(incomingPulseOxbyte, 7)) {
      byteCntPulse++;
    }
  }

}

//this gets executed after the android device has sent you a prompt
void measureRR(byte flag, byte numOfValues) {
 triggerRR();
 //the reset pin of the MSP430 inside the pulse oximeter is held low throughout the measurement process of the RR monitor
  //reset the pulse oximeter after/during the measurement because otherwise it freaks out and thinks you're dead due to the arteries getting compressed by the blood pressure monitor and the pulses disappearing
  digitalWrite(RST_PULSEOX, LOW);
  
}

void triggerOx(){
//function to trigger the pulse oximeter button
   digitalWrite(TRIG_PULSEOX,HIGH);
   pulseOxTrigTmr=micros();
   triggeredOx=true;
 }

void triggerRR(){
//trigger the blood pressure monitor button
   digitalWrite(TRIG_RR, HIGH);
  RRtrigTmr=micros();
  triggered=true;
}

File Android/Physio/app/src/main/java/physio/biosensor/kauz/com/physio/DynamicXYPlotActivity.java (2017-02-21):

/*
 * Copyright 2012 AndroidPlot.com
 *
 *    Licensed under the Apache License, Version 2.0 (the "License");
 *    you may not use this file except in compliance with the License.
 *    You may obtain a copy of the License at
 *
 *        http://www.apache.org/licenses/LICENSE-2.0
 *
 *    Unless required by applicable law or agreed to in writing, software
 *    distributed under the License is distributed on an "AS IS" BASIS,
 *    WITHOUT WARRANTIES OR CONDITIONS OF ANY KIND, either express or implied.
 *    See the License for the specific language governing permissions and
 *    limitations under the License.
 */

package physio.biosensor.kauz.com.physio;

import android.Manifest;
import android.app.Activity;
import android.bluetooth.BluetoothDevice;
import android.content.BroadcastReceiver;
import android.content.Context;
import android.content.Intent;
import android.content.IntentFilter;
import android.content.pm.PackageManager;
import android.graphics.Color;
import android.hardware.Sensor;
import android.hardware.SensorManager;
import android.os.Bundle;
import android.os.PowerManager;
import android.support.v4.app.ActivityCompat;
import android.support.v4.content.ContextCompat;
import android.view.View;
import android.widget.AdapterView;
import android.widget.ArrayAdapter;
import android.widget.CheckBox;
import android.widget.CompoundButton;
import android.widget.Spinner;
import android.widget.TextView;
import android.widget.Toast;

import com.androidplot.Plot;
import com.androidplot.util.PlotStatistics;
import com.androidplot.util.Redrawer;
import com.androidplot.xy.BoundaryMode;
import com.androidplot.xy.LineAndPointFormatter;
import com.androidplot.xy.SimpleXYSeries;
import com.androidplot.xy.XYAxisType;
import com.androidplot.xy.XYPlot;
import com.androidplot.xy.XYStepMode;

import java.io.BufferedWriter;
import java.io.File;
import java.io.FileWriter;
import java.io.IOException;
import java.text.DecimalFormat;
import java.util.ArrayList;
import java.util.Arrays;
import java.util.Calendar;
import java.util.List;

import at.abraxas.amarino.Amarino;
import at.abraxas.amarino.AmarinoIntent;

// Monitor the phone's orientation sensor and plot the resulting azimuth pitch and roll values.
// See: http://developer.android.com/reference/android/hardware/SensorEvent.html
public class DynamicXYPlotActivity extends Activity
{
    //sampling rates
    static private final int FsP=60;
    static private final int FsE=125;
    static private final int FsR=20;
    static private final int XaxisSecP=5;
    static private final int XaxisSecE=5;
    static private final int XaxisSecR=20;
    boolean recordEnable = false;
    PowerManager.WakeLock wL;

    boolean measuringRR = false;
    // private static final String TAG = "SensorGraph";

    // change this to your Bluetooth device address -1th: BILEX HC-05 "EEG2",
    // 0th: BILEX HC05 "EEG", 1st: HC05 on board (black box), 2nd:
    // RN42 3rd: no idea
    // get a variable from UserInput class
    public static String DEVICE_ADDRESS = null;// "20:13:04:23:03:56";//"EEG2"//"00:06:66:45:0F:3E";//RN42//"00:12:09:20:02:98";//EEG
    private ArduinoReceiver data = new ArduinoReceiver();

    File outputFile; //for recording

    private static final int REQUEST_WRITE_STORAGE = 112;

    private static final int HISTORY_SIZE_E = FsE * XaxisSecE;            // number of points to plot in history for ECG
    private static final int HISTORY_SIZE_R = FsR * XaxisSecR;            // respiration et al
    private static final int HISTORY_SIZE_P = FsP * XaxisSecP;              //pulse oximeter
    private SensorManager sensorMgr = null;
    private Sensor orSensor = null;

    //private XYPlot aprLevelsPlot = null;
    private XYPlot aprHistoryPlot = null;
    private XYPlot aprHistoryPlot2 = null;
    private XYPlot aprHistoryPlot3 = null;

    private CheckBox hwAcceleratedCb;
    private CheckBox showFpsCb;
    private CheckBox recordingCb;
    //private SimpleXYSeries aprLevelsSeries = null;

    String Channel = "GSR";
    //private SimpleXYSeries CH1Series;
    // private SimpleXYSeries CH2Series;
    private TextView mValueTV;
    private TextView HR_TV;
    private TextView SPO2_TV;
    private TextView Resp_TV;
    private TextView RR_TV;
    private TextView Temp_TV;
    List<String> chanList;
    private Spinner G4spinner;

    private SimpleXYSeries CH1HistorySeries = null;
    private SimpleXYSeries CH2HistorySeries = null;
    private SimpleXYSeries CH3HistorySeries = null;

    private Redrawer redrawer;
    private Redrawer redrawer2;
    private Redrawer redrawer3;

    @Override
    public void onRequestPermissionsResult(int requestCode, String[] permissions, int[] grantResults) {
        super.onRequestPermissionsResult(requestCode, permissions, grantResults);
        switch (requestCode)
        {
            case REQUEST_WRITE_STORAGE: {
                if (grantResults.length > 0 && grantResults[0] == PackageManager.PERMISSION_GRANTED)
                {
                    //reload my activity with permission granted or use the features what required the permission
                } else
                {
                    Toast.makeText(DynamicXYPlotActivity.this, "The app was not allowed to write to your storage. Hence, it cannot function properly. Please consider granting it this permission", Toast.LENGTH_LONG).show();
                }
            }
        }

    }

    /** Called when the activity is first created. */
    @Override
    public void onCreate(Bundle savedInstanceState) {
//ask for permission to write to storage
        boolean hasPermission = (ContextCompat.checkSelfPermission(DynamicXYPlotActivity.this,
                Manifest.permission.WRITE_EXTERNAL_STORAGE) == PackageManager.PERMISSION_GRANTED);
        if (!hasPermission) {
            ActivityCompat.requestPermissions(DynamicXYPlotActivity.this,
                    new String[]{Manifest.permission.WRITE_EXTERNAL_STORAGE},
                    REQUEST_WRITE_STORAGE);
        }

        // #78 wake-lock to keep that open!
        PowerManager pM = (PowerManager) getSystemService(Context.POWER_SERVICE);
        wL = pM.newWakeLock(PowerManager.FULL_WAKE_LOCK, "tag whatever");
        super.onCreate(savedInstanceState);
        wL.acquire(); // can also be put into onResume() method
        // receive Intent with BT-device extra from DiscoveryActivity and decode
        // device name and address of the found module
        Intent fromDiscovery = getIntent();
        final BluetoothDevice device = fromDiscovery
                .getParcelableExtra(BluetoothDevice.EXTRA_DEVICE); // get the
        // struct
        // type
        // thingy.
        String deviceName = device.getName();
        String deviceAddress = device.getAddress();



        DEVICE_ADDRESS = deviceAddress;


        setContentView(R.layout.dynamicxyplot_example);
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

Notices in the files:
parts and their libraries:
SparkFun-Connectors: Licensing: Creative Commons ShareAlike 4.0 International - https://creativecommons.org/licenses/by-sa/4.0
